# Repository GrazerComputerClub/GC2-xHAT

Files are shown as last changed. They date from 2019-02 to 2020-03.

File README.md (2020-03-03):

# GC2-xHAT
Raspberry Pi Zero Extended HAT for Raspjamming and other Events

## Features

- **7-Segment Display** - 4-Digits TM1637 (Proprietary 2-Wire Bus)  
  CLK  ... GPIO23  
  DIO  ... GPIO24   
- **Sensors**
	 - DHT11/DHT22/AM2302 (Proprietary 1-Wire Bus) - Humidity & Temperature (GPIO22, External Pull-up)
	 - AMD2320/AMD2322 (I2C Bus) - Humidity & Temperature
	 - DS18B20 (1-Wire Bus) - Temperature (GPIO04, External Pull-up)
	 - HC-SR04 (Proprietary Interface) - Distance  
             TRIGGER ... GPIO17  
             ECHO ... GPIO27 (External 5V to 3V divider for input)  
- **Traffic Light** 
	 - LED red (GPIO16, Active High, Default off)
	 - LED yellow/orange (GPIO20, Active High, Default off)
	 - LED green (GPIO21, Active High, Default off)
- **Switches** 
 	 - S1 (GPIO13, Active High, Default Low)
	 - S2 (GPIO19, Active High, Default Low)
	 - S3 (GPIO26, Active High, Default Low)
- **Buzzer** (GPIO18, Active High, Default off) 
- **ATmega 328P Sockel** Programming/Testing  
  RESET ... GPIO25 (Active Low, Default Low with no Power, Default High with Power)  
  MOSI  ... GPIO10  
  MISO  ... GPIO09  
  SCK   ... GPIO11  
- **ESP-01 Sockel** (ESP8266) Programming/Testing  
  RST   ... GPIO06 (Active Low, Default High)  
  GPIO0 ... GPIO12 (High ... Programming, Low ... Flash-Boot, Default Low)  
  TXD   ... GPIO14  
  RXD   ... GPIO15  
- Power Switch for ATmega and ESP-01 (GPIO05, Active Low, Default off)
- HAT EEPROM (I2C Bus)  
	 I2C0, A0-A2 Low

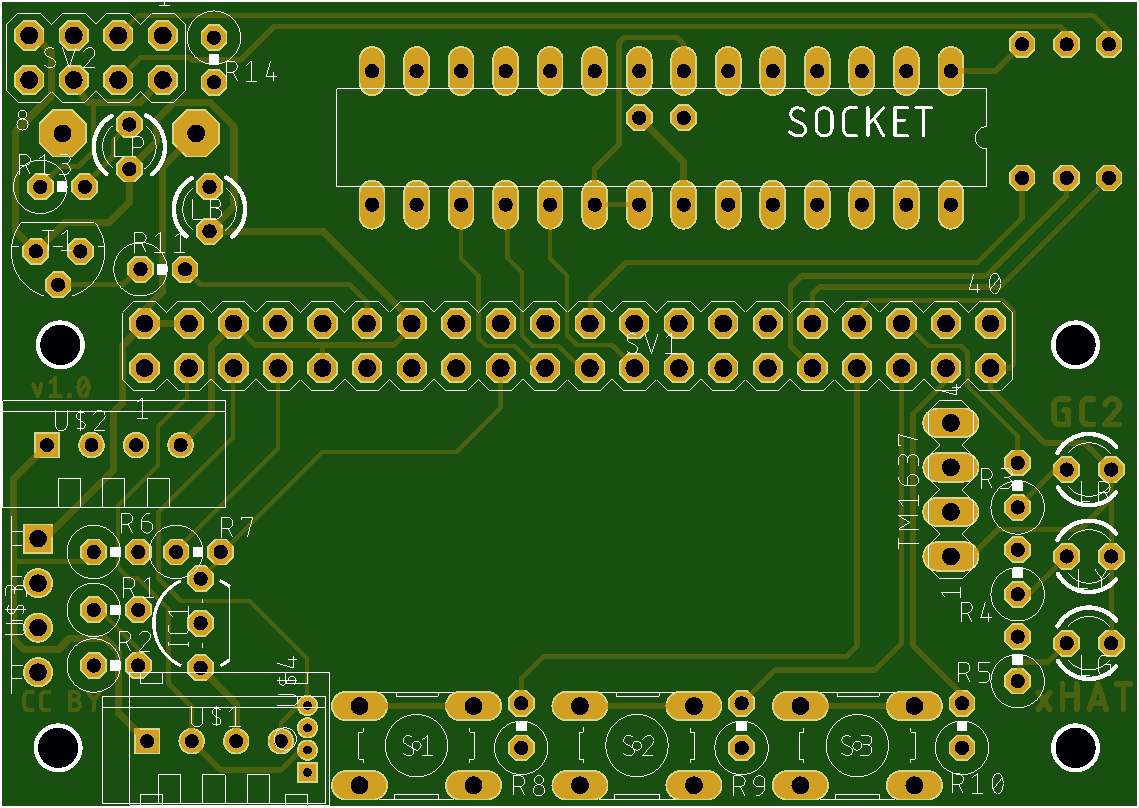
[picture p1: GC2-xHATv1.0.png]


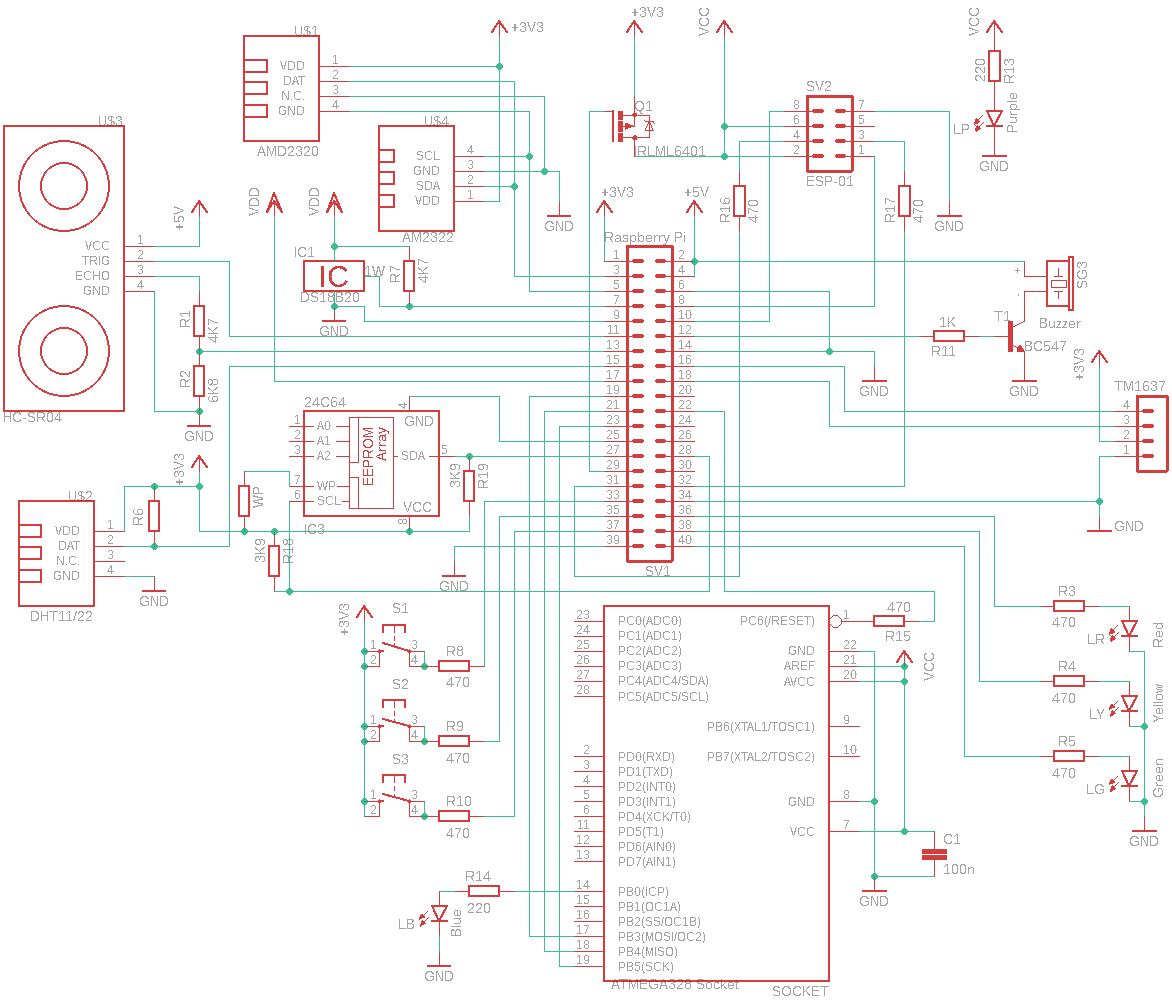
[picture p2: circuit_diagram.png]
Circuit diagram


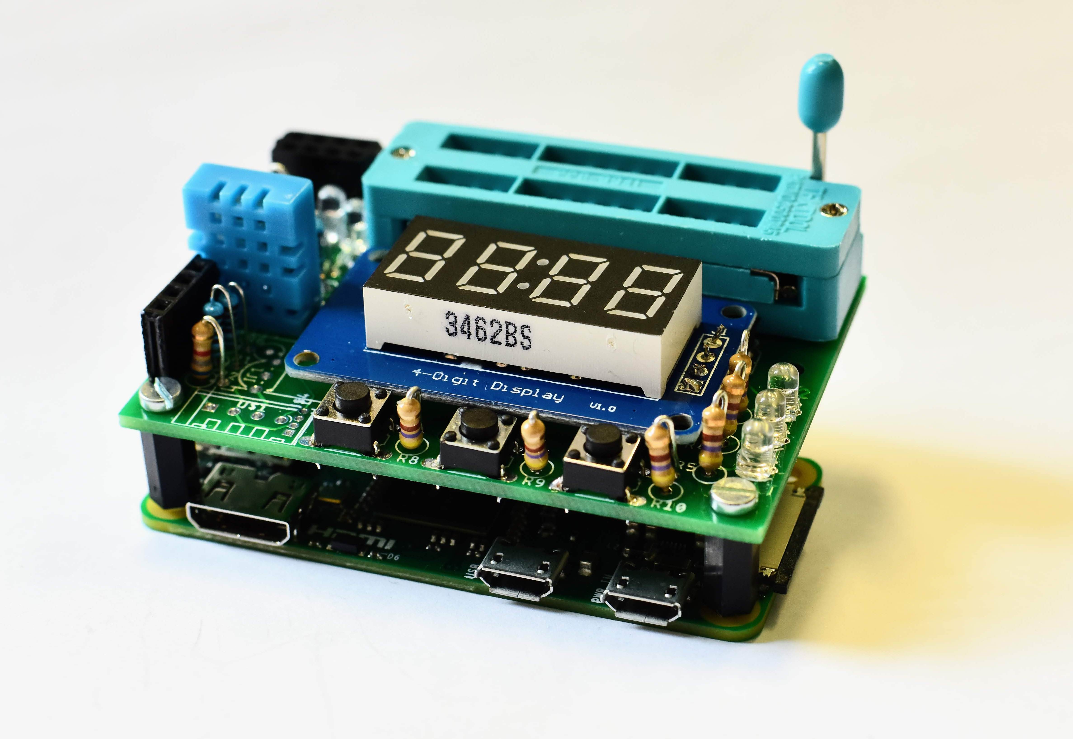
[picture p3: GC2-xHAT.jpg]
GC2-xHAT


## Assembling

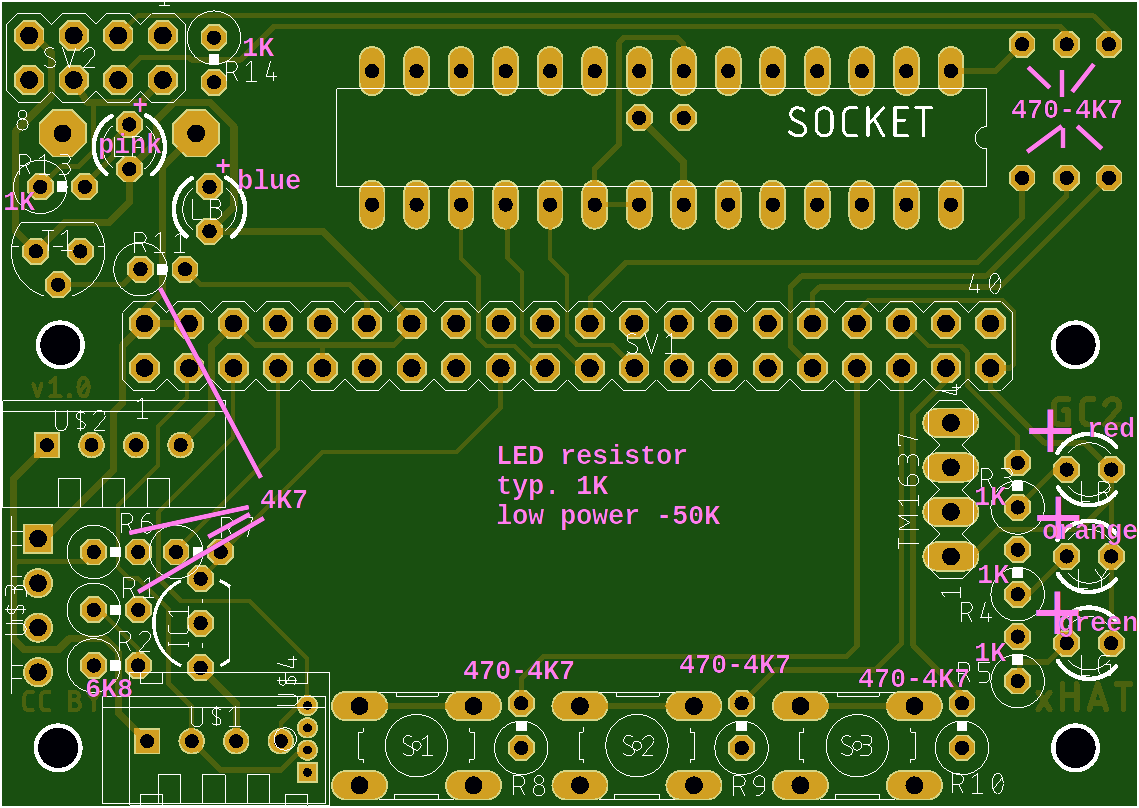
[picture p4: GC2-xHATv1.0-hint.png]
GC2-xHAT PCB with assambling hints


Order recommendation:

- Start with SMD components (FET, EEPROM, resistors)
- ...
- Switches
- 40-pin Header 
- 8-pin Header (need soldering before Buzzer!) 
- Buzzer 
- 14-pin socket 100nF capacitor backside
- 14-pin Socket
- Place electrical tape on backside of 7-seg display
- 7-seg display

Hints: 
- Swiches: Only solder two opposite contacts 
- Standing resistors: Solder short wire first
- Solder R8, R9, R10 lying on backside (to not disturb switches) or
- Advanced people can solder SMD1206 resistors instead of classic standing ones 
- Buzzer can be very loud, solder 47 KOhm resistor for silent operation
- Solder DS18B20 with maximum wire length to keep it away from board heat sources  

### Components list
	
10 x Resistor 470 o. 1K  (LED*: R3, R4, R13, R14 ; Protect: R8, R9, R10, R15, R16, R17)  
 4 x Resistor 4K7 (5V->3V: R1 ; Pull-up: R6, R7 ; Transistor base: R11)  
 1 x Resistor 6K8 (5V->3V: R2)  
 1 x Resistor 47K (Green LED: R5*)  
 3 x Tactile switch 6x6mm (S1, S2, S3)  
 1 x LED red 3mm (LR)  
 1 x LED yellow/orange 3mm (LY)  
 1 x LED green 3mm (YG)  
 1 x LED blue 3mm (LB)  
 1 x LED pink 3mm (LP)  
 1 x Transistor BC547B (T1)  
 1 x Female pin header socket 2x4 (SV2)  
 1 x Female pin header socket 1x4 (U$3)  
 1 x Female pin header socket 2x20 (SV1)  
 1 x 28-Pin DIP-Socket o. 28-Pin ZIF-Socket (0.3''/7.62mm Narrow)  
 1 x DHT11 o. DHT22 o. AM2302 (U$2)  
 1 x AM2322 o. AM2320  (U$4 / U$1)  
 1 x DS18B20 (IC1)  
 1 x TM1637 4 Digi LED display modul (GND, VCC, DIO, CLK)  
 1 x Buzzer (O 12mm, 7.2mm holes) (SG3)  
 1 x FET IRLML6401 (Q1)  
 1 x EEPROM STM M24C64-WMN6 (24C64) **  
 2 x SMD 1206 resistor 3K9 (R18, R19)  
 1 x Capacity 100nF (C1)  
 2 x Spacer 1 cm, M2.5  
 2 x Bolt M2.5

\* Please choose LED resistor corresponding to LED type and 3.3 V, usually 1 KOhm is ok, but our green LED is a low current type, so even 47K makes a satisfying light  
\** Different sizes and manufacturers are possible if EEPROM comply with the Raspberry Pi HAT EEPROM specification (8 bit data, 16 bit address, I2C @ 100 kHz, 3.3 V)

### China-Bezugsquellen Spezialkomponenten:

DHT11, DHT22, AM2320, AM2322, TM1637, Buzzer  
[RoarKit](https://de.aliexpress.com/store/1266255)

### DE-Bezugsquellen Spezialkomponenten:

DHT11: 
* [Reichelt](https://www.reichelt.com/de/en/developer-boards-temperature-humidity-sensor-debo-dht-11-p224221.html) 
* [AZ-Delivery](https://www.az-delivery.de/collections/temperatursensoren/products/5-x-dht11-temperatursensor)  
* [Amazon](https://www.amazon.de/s?k=DHT11)

DHT22: 
* [Reichelt](https://www.reichelt.com/de/en/development-boards-temperature-humidity-sensor-debo-dht-22-p224218.html) 
* [AZ-Delivery](https://www.az-delivery.de/collections/temperatursensoren/products/dht22)   
* [Amazon](https://www.amazon.de/s?k=DHT22)

AM2320: 
* [Amazon](https://www.amazon.de/s?k=AM2320) 

DS18B20: 
* [Reichelt](https://www.reichelt.com/de/en/digital-thermometer-1-wire-0-5-c-to-92-ds-18b20-p58169.html) 
* [AZ-Delivery](https://www.az-delivery.de/collections/temperatursensoren/products/5ersetds18b20)  
* [Amazon](https://www.amazon.de/s?k=18B20)

TM1637: 
* [AZ-Delivery](https://www.az-delivery.de/products/4-digit-display)
* [Amazon](https://www.amazon.de/s?k=TM1637)

Buzzer:
* [Amazon](https://www.amazon.de/s?k=Beeper+5V)

## Case

### Recommanded 3d-printer case for Raspberry Pi B+, 2B, 3B, 3B+ 

[Raspberry Pi case (model B+ / 2 / 3)](https://www.thingiverse.com/thing:559858) by Adrien12  is licensed under the Attribution - Non-Commercial - Share Alike license.
[BY-NC-SA](http://creativecommons.org/licenses/by-nc-sa/3.0/)
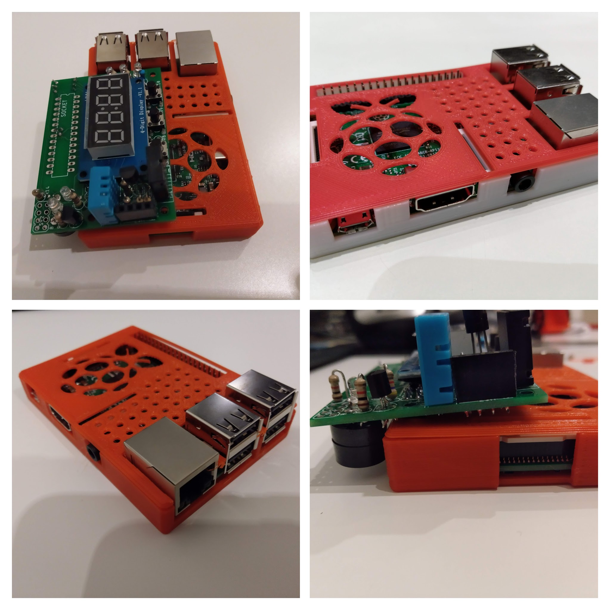
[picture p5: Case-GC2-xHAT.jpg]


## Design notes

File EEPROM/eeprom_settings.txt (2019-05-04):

########################################################################
# EEPROM settings text file
#
# Edit this file for your particular board and run through eepmake tool,
# then use eepflash tool to write to attached HAT ID EEPROM 
#
# Tools available:
#  eepmake   Parses EEPROM text file and creates binary .eep file
#  eepdump   Dumps a binary .eep file as human readable text (for debug)
#  eepflash  Write or read .eep binary image to/from HAT EEPROM
#
########################################################################

########################################################################
# Vendor info

# 128 bit UUID. If left at zero eepmake tool will auto-generate
# RFC 4122 compliant UUID
product_uuid 00000000-0000-0000-0000-000000000000

# 16 bit product id
product_id 0x6C20

# 16 bit product version
product_ver 0x0100

# ASCII vendor string  (max 255 characters)
vendor "Grazer Computer Club (Austria)"

# ASCII product string (max 255 characters)
product "GC2-xHAT (Raspjamming HAT)"

########################################################################
# GPIO bank settings, set to nonzero to change from the default.
# NOTE these setting can only be set per BANK, uncommenting any of
# these will force the bank to use the custom setting.

# drive strength, 0=default, 1-8=2,4,6,8,10,12,14,16mA, 9-15=reserved
gpio_drive 0

# 0=default, 1=slew rate limiting, 2=no slew limiting, 3=reserved
gpio_slew 0

# 0=default, 1=hysteresis disabled, 2=hysteresis enabled, 3=reserved
gpio_hysteresis 0

# If board back-powers Pi via 5V GPIO header pins:
# 0 = board does not back-power
# 1 = board back-powers and can supply the Pi with a minimum of 1.3A
# 2 = board back-powers and can supply the Pi with a minimum of 2A
# 3 = reserved
# If back_power=2 then USB high current mode will be automatically 
# enabled on the Pi
back_power 0

########################################################################
# GPIO pins, uncomment for GPIOs used on board
# Options for FUNCTION: INPUT, OUTPUT, ALT0-ALT5
# Options for PULL: DEFAULT, UP, DOWN, NONE
# NB GPIO0 and GPIO1 are reserved for ID EEPROM so cannot be set

#         GPIO  FUNCTION  PULL
#         ----  --------  ----
#setgpio  2     INPUT     DEFAULT
#setgpio  3     INPUT     DEFAULT
#setgpio  4     INPUT     DEFAULT
#setgpio  5     INPUT     DEFAULT
#setgpio  6     INPUT     DEFAULT
#setgpio  7     INPUT     DEFAULT
#setgpio  8     INPUT     DEFAULT
#setgpio  9     INPUT     DEFAULT
#setgpio  10    INPUT     DEFAULT
#setgpio  11    INPUT     DEFAULT
#setgpio  12    INPUT     DEFAULT
#setgpio  13    INPUT     DEFAULT
#setgpio  14    INPUT     DEFAULT
#setgpio  15    INPUT     DEFAULT
#setgpio  16    INPUT     DEFAULT
#setgpio  17    INPUT     DEFAULT
#setgpio  18    INPUT     DEFAULT
#setgpio  19    INPUT     DEFAULT
#setgpio  20    INPUT     DEFAULT
#setgpio  21    INPUT     DEFAULT
#setgpio  22    INPUT     DEFAULT
#setgpio  23    INPUT     DEFAULT
#setgpio  24    INPUT     DEFAULT
#setgpio  25    INPUT     DEFAULT
#setgpio  26    INPUT     DEFAULT
#setgpio  27    INPUT     DEFAULT

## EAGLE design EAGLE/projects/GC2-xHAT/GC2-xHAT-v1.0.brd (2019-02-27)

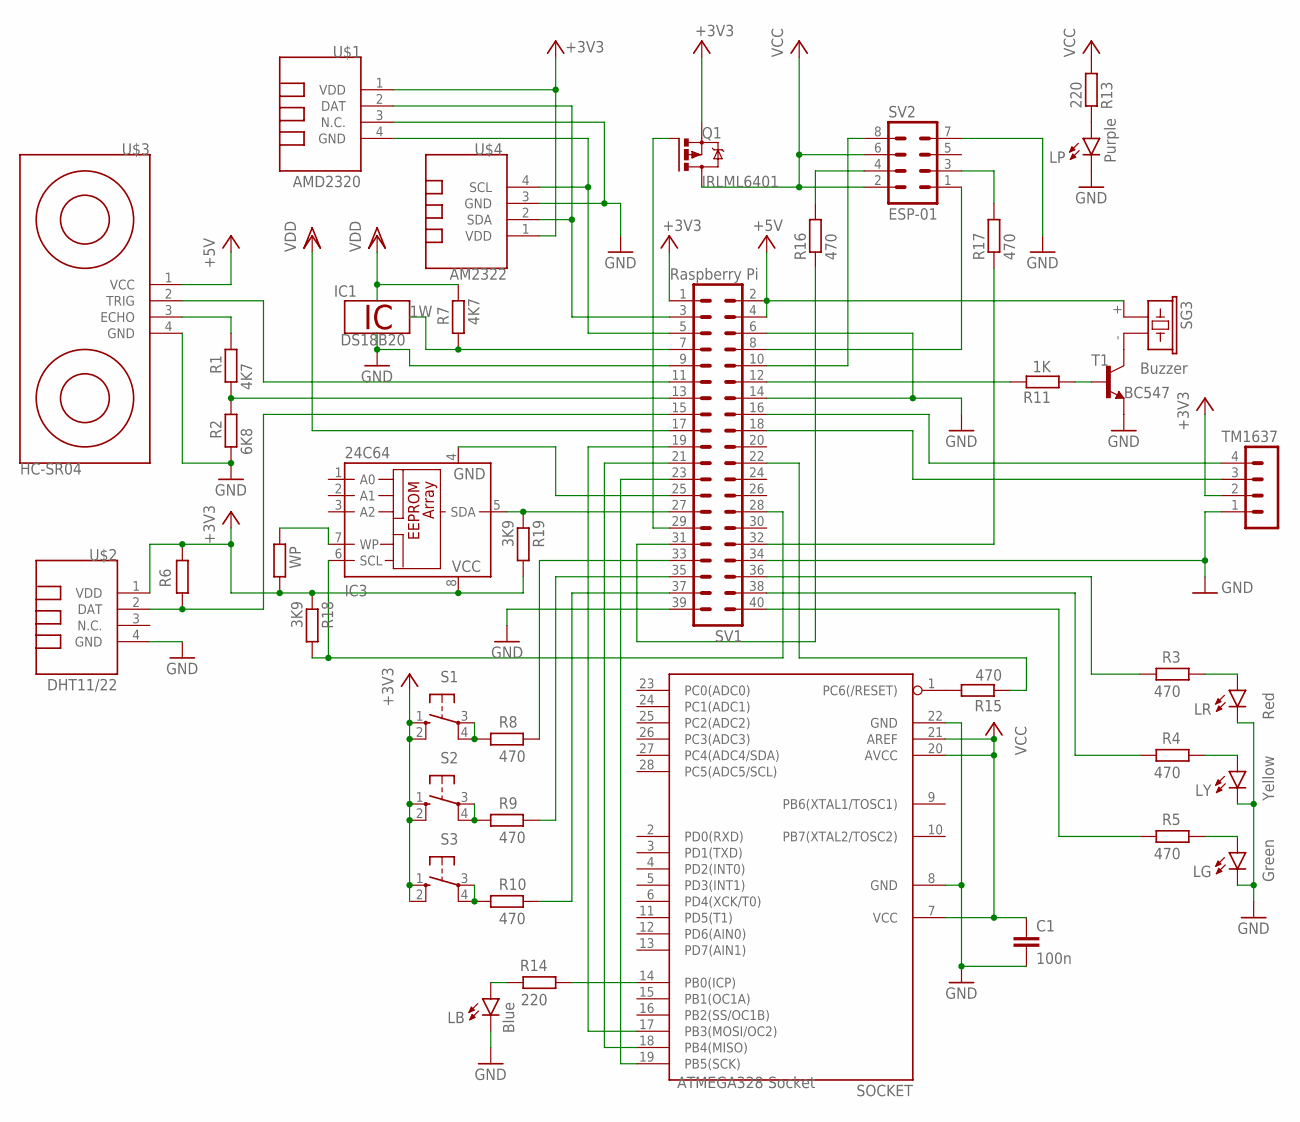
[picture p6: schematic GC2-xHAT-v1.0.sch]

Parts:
C1: 100n; C025-024X044
IC1: DS18B20; TO92-
IC3: 24C64; SO-08
LB: Blue; LED3MM
LG: Green; LED3MM
LP: Purple; LED3MM
LR: Red; LED3MM
LY: Yellow; LED3MM
Q1: IRLML6401; MICRO3
R1, R6, R7: 4K7; 0309V
R2: 6K8; 0309V
R3, R4, R5, R8, R9, R10: 470; 0309V
R11: 1K; 0309V
R13, R14: 220; 0309V
R15, R16, R17: 470; 0204/7
R18, R19: 3K9; R1206
S1, S2, S3: 10-XX; B3F-10XX
SG3: Buzzer; F/CM12P
SOCKET: ATMEGA328 Socket; DIL28-3
SV1: Raspberry Pi; MA20-2
SV2: ESP-01; MA04-2
SW: WP; M1406
T1: BC547; TO92
TM1637: MA04-1
U$1: AMD2320; TEMP-HUM-SENSOR-DHT11
U$2: DHT11/22; TEMP-HUM-SENSOR-DHT11
U$3: HC-SR04; ULTRASONIC-HC-SR04#V
U$4: AM2322; TEMP-HUM-SENSOR-AM2322

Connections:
1W: IC1.2 (1W), R7.1, SV1.7
+3V3: IC3.8 (VCC), Q1.2 (S), R6.1, R18.1, R19.2, S1.1 (S), S1.2 (S1), S2.1 (S), S2.2 (S1), S3.1 (S), S3.2 (S1), SV1.1, SW.1, TM1637.2, U$1.1 (VDD), U$2.1 (VDD), U$4.1 (VDD)
+5V: SG3.+ (1), SV1.2, SV1.4, U$3.1 (VCC)
GND: C1.2, IC1.1 (GND), LB.K (C), LG.K (C), LP.K (C), LR.K (C), LY.K (C), R2.1, SOCKET.8 (GND), SOCKET.22 (GND), SV1.6, SV1.9, SV1.14, SV1.34, SV1.39, SV2.7, T1.1 (E), TM1637.1, U$1.3 (N.C.), U$2.4 (GND), U$3.4 (GND), U$4.3 (GND)
unnamed: LY.A, R4.1
unnamed: SV1.3, U$1.2 (DAT), U$4.2 (SDA)
unnamed: SV1.5, U$1.4 (GND), U$4.4 (SCL)
unnamed: R1.1, R2.2, SV1.13
unnamed: R9.1, S2.3, S2.4 (P1)
unnamed: SV1.11, U$3.2 (TRIG)
unnamed: R8.1, S1.3, S1.4 (P1)
unnamed: R11.1, T1.2 (B)
unnamed: R17.2, SV2.3
unnamed: SOCKET.17 (PB3(MOSI/OC2)), SV1.19
unnamed: SOCKET.18 (PB4(MISO)), SV1.21
unnamed: SOCKET.19 (PB5(SCK)), SV1.23
unnamed: LP.A, R13.2
unnamed: LG.A, R5.1
unnamed: R8.2, SV1.33
unnamed: R9.2, SV1.35
unnamed: R10.2, SV1.37
unnamed: R17.1, SV1.32
unnamed: Q1.1 (G), SV1.29
unnamed: R15.2, SOCKET.1 (PC6(/RESET))
unnamed: R14.1, SOCKET.14 (PB0(ICP))
unnamed: R10.1, S3.3, S3.4 (P1)
unnamed: R16.2, SV2.4
unnamed: SV1.8, SV2.1
unnamed: SV1.10, SV2.8
unnamed: R11.2, SV1.12
unnamed: R15.1, SV1.22
unnamed: SV1.16, TM1637.4
unnamed: R6.2, SV1.15, U$2.2 (DAT)
unnamed: LB.A, R14.2
unnamed: IC3.5 (SDA), R19.1, SV1.27
unnamed: IC3.6 (SCL), R18.2, SV1.28
unnamed: R16.1, SV1.31
unnamed: R4.2, SV1.38
unnamed: R3.2, SV1.36
unnamed: LR.A, R3.1
unnamed: SG3.- (2), T1.3 (C)
unnamed: R1.2, U$3.3 (ECHO)
unnamed: SV1.18, TM1637.3
unnamed: IC3.7 (WP), SW.2
unnamed: R5.2, SV1.40
unnamed: IC3.4 (GND), SV1.25
VCC: C1.1, Q1.3 (D), R13.1, SOCKET.7 (VCC), SOCKET.20 (AVCC), SOCKET.21 (AREF), SV2.2, SV2.6
VDD: IC1.3 (VDD), R7.2, SV1.17

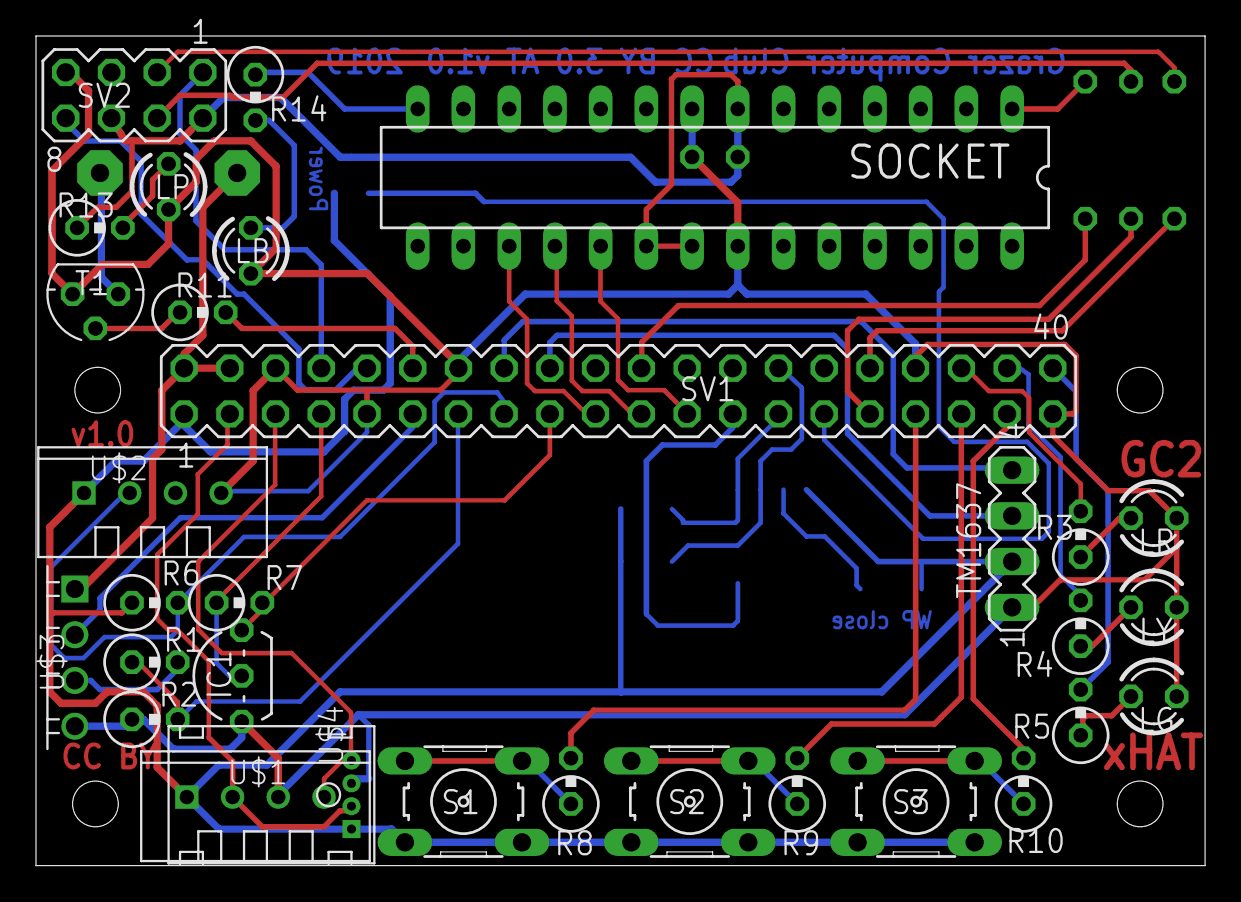
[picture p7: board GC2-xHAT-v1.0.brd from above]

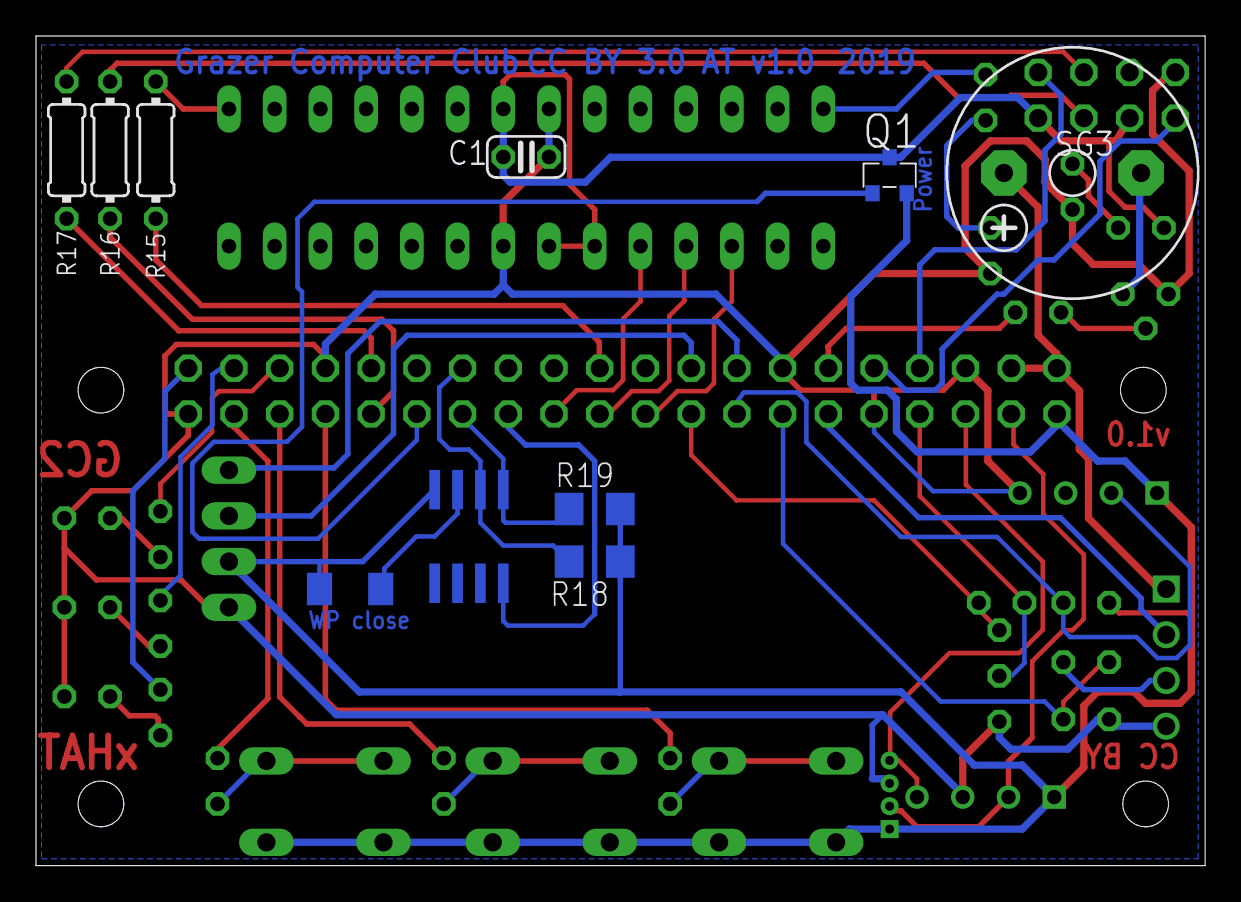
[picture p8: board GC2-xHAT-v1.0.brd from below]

Board: 2 copper layers, 64.9 x 46.1 mm, 41 parts (10 on the bottom side), 48 nets.

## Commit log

2019-02-27 Eagle PCB Design Version 1.0
    [GC2-xHAT-v1.0.brd, GC2-xHAT-v1.0.sch]
2020-05-03 TonalBuzzer sample

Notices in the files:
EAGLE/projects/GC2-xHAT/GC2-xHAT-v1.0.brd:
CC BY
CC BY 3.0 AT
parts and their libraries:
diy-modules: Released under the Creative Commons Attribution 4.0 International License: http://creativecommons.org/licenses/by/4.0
